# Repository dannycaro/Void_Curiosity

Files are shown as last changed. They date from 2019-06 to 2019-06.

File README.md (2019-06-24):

# Void_Curiosity

VoidCuriosity es el proyecto que están realizando un grupo de alumnos de 1º de Bachillerato del IES Vicente Aleixandre para la asignatura de Tecnología Industrial I y TIC I, basado en el proyecto abierto creado por @felixstdp, el cual se puede encontrar en [bricolabs](https://bricolabs.cc/wiki/proyectos/curiosity_btl), y en la versión creada por @javacasm

El proyecto consiste en un réplica a escala del famoso robot de investigación denominado como Curiosity de la NASA. Es un vehículo de exploración que puede superar terrenos difíciles y obstáculos con los que tendrían problemas otro tipo de vehículos. 

Para más información sobre nuestro proyecto podéis visitar la [web de nuestro proyecto](https://sites.google.com/iesvaleix.com/voidcuriosity)

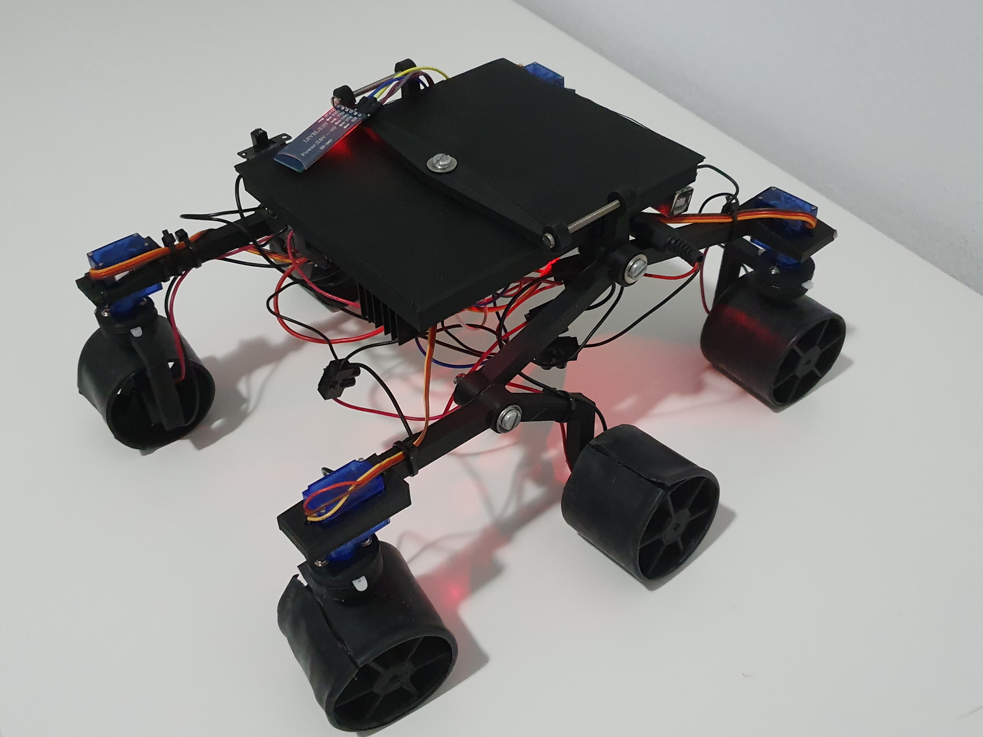
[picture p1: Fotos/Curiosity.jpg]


En el repositorio puedes encontrar:
- [Memoria del proyecto en PDF](https://github.com/dannycaro/Void_Curiosity/blob/master/Memoria%20curiosity.pdf)
- [Código de Arduino](https://github.com/dannycaro/Void_Curiosity/blob/master/Software/C%C3%B3digo%20Arduino/C%C3%B3digo%20v3.0)
- [Apk de la Aplicación](https://github.com/dannycaro/Void_Curiosity/blob/master/Software/VoidCuriosity.apk)
- [Aia de la Aplicación](https://github.com/dannycaro/Void_Curiosity/blob/master/Software/VoidCuriosity.aia)
- [Esquema electronico de conexión](https://github.com/dannycaro/Void_Curiosity/blob/master/Hardware/Esquema%20electrico%20definitivo%20.png)
- [Esquema en protoboard](https://github.com/dannycaro/Void_Curiosity/blob/master/Hardware/Protoboard%20definitiva.png)
- [Esquema en formato Fritzing fzz](https://github.com/dannycaro/Void_Curiosity/blob/master/Hardware/Curiosity_FINAL%20.fzz)

## LICENCIA
Este proyecto fue desarrollado durante el curso 2018/2019 en el IES Vicente Aleixandre de Sevilla en 1º de Bachillerato de Tecnología Industrial por Danny Caro, Alejandro Lauriño y Raúl Gimeno con el apoyo de su profesor Jose Pujol. Se distribuye con licencia [Creative Commons Attribution-ShareAlike 4.0 International License](http://creativecommons.org/licenses/by-sa/4.0/)

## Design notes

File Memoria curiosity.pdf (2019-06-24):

# Memoria del Voidcuriosity

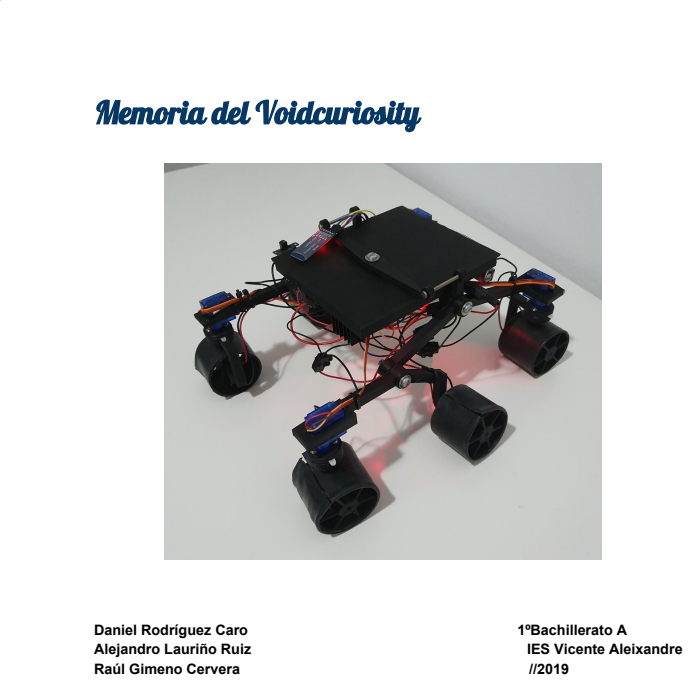
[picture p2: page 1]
Daniel Rodríguez Caro; 1ºBachillerato A; Alejandro Lauriño Ruiz; IES Vicente Aleixandre; Raúl Gimeno Cervera

Memoria proyecto curiosity

## Índice

Índice | 1
1. Finalidad del Sistema | 2
2. Hardware | 2
3. Software | 4
4. Funcionamiento | 6
5. Evaluación | 6
6. Bibliografía y webgrafía | 7

## 1. Finalidad del Sistema

El proyecto es una reproducción a escala 1:10 del astromóvil lanzado en la misión Mars Science Laboratory.
En un principio, enviamos las órdenes para mover los servos y hacer girar los motores a través del monitor serie, con el robot conectado al ordenador (pmv).
Cuando ya teníamos eso, pasamos a usar un módulo bluetooth y App Inventor para controlarlo remotamente desde un dispositivo móvil.
El sistema consta de 6 motores cc motrices (N20 dc motors) y 4 servomotores directrices (9g servo), además del mecanismo rocker-boogie que le permitirá superar obstáculos no muy complejos con facilidad. Gracias a este sistema y la estabilidad del móvil, podrá desenvolverse sin dificultades en superficies escarpadas y terrenos complejos.

## 2. Búsqueda de información

La mayor parte de la información ha sido conseguida en el repositorio del proyecto (https://bricolabs.cc/wiki/proyectos/curiosity_btl) que se encuentra en la web de Bricolabs y en los Github’s de @felixstpd y @javacasm (https://github.com/javacasm/curiosity_btl) los cuáles han sido una ayuda fundamental a la hora de realizar el proyecto.

## 3. Hardware

a. Esquema de entradas y salidas

b. Lista de materiales
Material | Cantidad
Placa Arduino MEGA | 1
Arduino sensor shield v5.0 | 1
L298 | 1
N20 dc motors | 6
9g servos | 4
18650 baterías | 2
Tornillería | General
c. Esquema de la protoboard

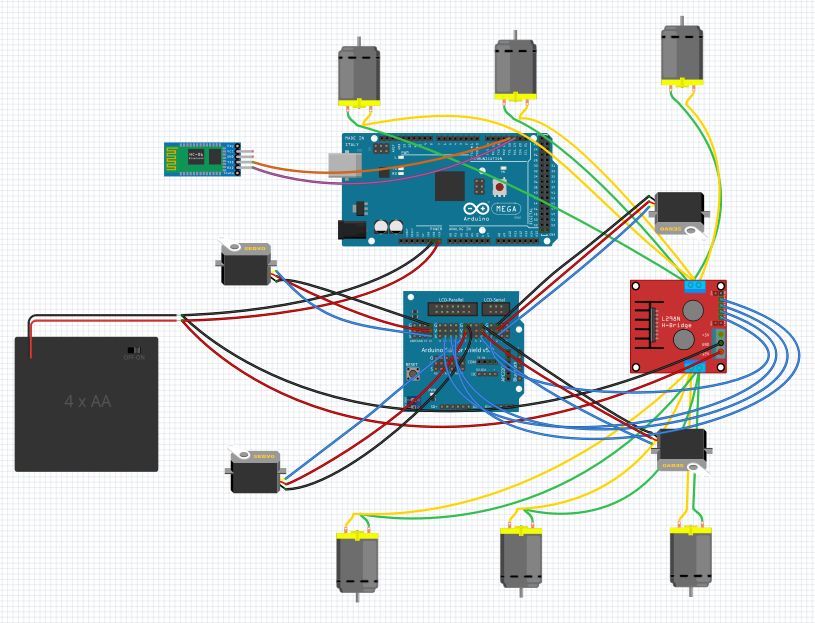
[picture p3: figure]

d. Esquema electrónico

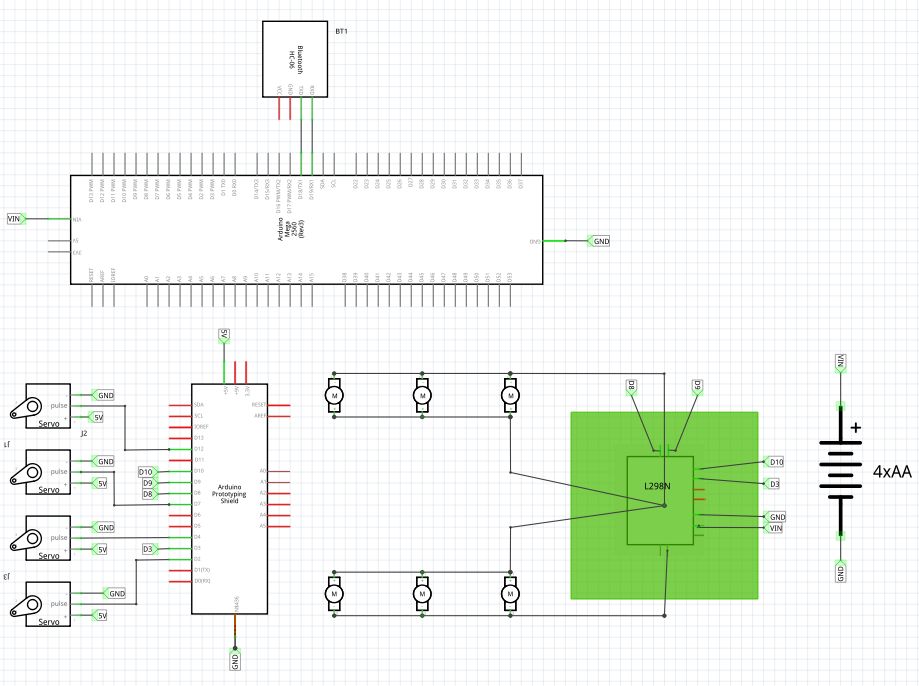
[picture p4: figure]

## 4. Software

/* Código v3.0
Proyecto Void Curiosity
Danny Caro
Alejandro Lauriño
Raúl Gimeno
1º BTO TIND-TIC
Basado en código de @javacasm
IES Vicente Aleixandre */

#include <Servo.h> //incluimos la librería para poder controlar los servomotores

//Definimos los pines de los servomotores
#define S1 12

#define S2 7

#define S3 4

#define S4 2

Servo s1, s2, s3, s4;

// Pines de control de los motores // Pines motor derecho
const int inA = 3;
const int inB = 10;
const int enA = 5;

// Pines motor izquierdo
const int inC = 9;
const int inD = 8;
const int enB = 6;

int value = 0; // variable para almacenar el valor numerico
int posS1, posS2, posS3, posS4; //Creamos las variables para almacenar la posición de los servos
int pasoServo = 5; // Incremento de posicion de los servos
int pwmValue = 0; // variable para enviar el codigo pwm al led

//Creamos una función para definir la posición inical de lo0s servos void setServosInitialState() {
posS1 = 97;
posS2 = 105;
posS3 = 98;
posS4 = 82;
}

// La velocidad va desde -255 a 255, con valores negativos moviendose hacia atras

int velocidad = 0;
int pasoVelocidad = 10; // Usaremos este incremento

// Nos permite dar velocidad a cada motor
void setSpeed(int enB, int speed) {
if (speed > 0) {
analogWrite(enB, speed);
}
else {
analogWrite(enB, - speed);
}
}

//Establecemos posicición de los servos y la velocidad de los motores void setState() {
setSpeed(enB, velocidad);
setSpeed(enA, velocidad);
s1.write(posS1);
s2.write(posS2);
s3.write(posS3);
s4.write(posS4);
}

// El motor gira en sentido horario void clockWise() {
digitalWrite(inA, LOW);
digitalWrite(inB, HIGH);
digitalWrite(inC, LOW);
digitalWrite(inD, HIGH);
}

// Función para que el motor gire en sentido antihorario void antiClockWise() {
digitalWrite(inA, HIGH);
digitalWrite(inB, LOW);
digitalWrite(inC, HIGH);
digitalWrite(inD, LOW);
}

void setup() {
// Configuramos los pines de los motores como salida pinMode(inA, OUTPUT);
pinMode(inB, OUTPUT);
pinMode(inC, OUTPUT);
pinMode(inD, OUTPUT);

// Configuramos los pines de los servos como salida pinMode(S1, OUTPUT);
pinMode(S2, OUTPUT);
pinMode(S3, OUTPUT);
pinMode(S4, OUTPUT);

// Configuramos las comunicaciones Serial1.begin(9600);

// Configuramos los servos s1.attach(S1);
s2.attach(S2);
s3.attach(S3);
s4.attach(S4);
setServosInitialState();
setState();
}

void loop() {
/*
Control de velocidad y giro por movimiento F el robot avanza
S detiene en seco
B el robot retrocede

Control de giro usando los servos L girar a la izquierda
R girar a la derecha
O servos rectos
*/

if (Serial1.available() > 0) {
char caracter = Serial1.read();
if (caracter >= '0' && caracter <= '9') {
//Acumula los datos numericos multiplicando por 10 el valor acumulado
value = (value * 10) + (caracter - '0'); // Resta 48 que es el valor decimal del 0 ASCII }
else if (caracter == '>') // uso > como finalizador
{
pwmValue = value; // Guarda el valor en la variable pwmValue value = 0; // Dejamos lista la variable para volver a escribir en ella }

else {
switch (caracter) {

case 'F': //Utilizamos para que el robot pueda caminar hacia delante clockWise();
velocidad = pwmValue;
break;
case 'B': //Utilizamos para que el robot pueda dar marcha atrás antiClockWise();
velocidad = pwmValue;
break;
case 'S': //Paramos los motores velocidad = 0;
break;
case 'L': // Mas giro a la izquierda posS1 -= pasoServo;
posS4 -= pasoServo;
posS3 += pasoServo;
posS2 += pasoServo;
break;
case 'O': // Ponemos los servomotores en la posición inicial setServosInitialState();
break;
case 'R': // Mas giro a la derecha
posS1 += pasoServo;
posS4 += pasoServo;
posS3 -= pasoServo;
posS2 -= pasoServo;
break;
}
}
// Vemos si nos hemos pasado de posiciones if (posS1 < 0) posS1 = 0;
if (posS2 < 0) posS2 = 0;
if (posS3 < 0) posS3 = 0;
if (posS4 < 0) posS4 = 0;
if (posS1 > 180) posS1 = 180; if (posS2 > 180) posS2 = 180;
if (posS3 > 180) posS3 = 180;
if (posS4 > 180) posS4 = 180;

// Vemos si nos pasamos en las velocidades
if (velocidad > 255 ) velocidad = 255;
if (velocidad < -255 ) velocidad = -255;

// Establecemos las posiciones de los servos y la velocidad de los motores setState();
}

## 5. Funcionamiento

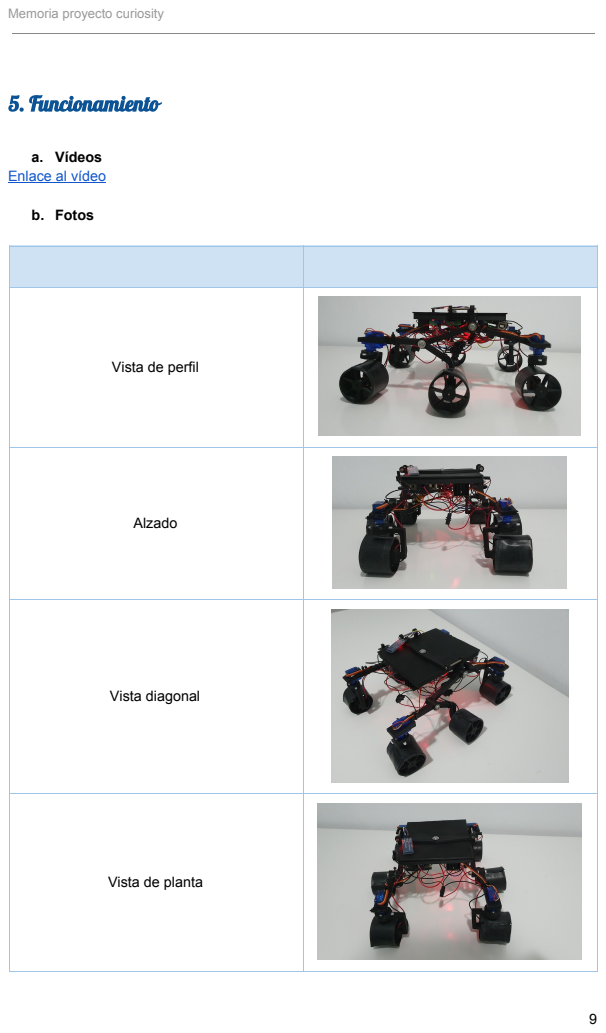
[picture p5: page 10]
b. Fotos

a. Vídeos
Enlace al vídeo (https://www.youtube.com/watch?v=UXL3HhqOG2k)

Vista de perfil

Alzado

Vista diagonal

Vista de planta

## 6. Evaluación

a. Qué funciona bien y qué se puede mejorar.
- Sistema rocker-bogie: El sistema funciona bien y consigue superar obstáculos de una altura del diámetro de la rueda más o menos. Podríamos mejorarlo haciendo que pase unos obstáculos de un poco más de inclinación.
b. Problemas que hemos tenido y soluciones.
- Cortocircuito: Tuvimos un cortocircuito al poner las pilas en el portapilas y entonces este se quemo. Solución: Revisamos todas las conexiones y utilizamos una fuente de alimentación.
- Pieza simétrica: Cuando hicimos la impresión 3D no hicimos la pieza simétrica de una de las patas, por lo que las ruedas quedaban mal posicionadas. Solución: Tuvimos que repetir la pieza haciéndola simétrica.
- Falta de pines PWM: Al comenzar el proyecto, en el hardware usábamos Arduino UNO pero nos faltaban pines PWM. Solución: Cambiamos Arduino UNO por el Arduino MEGA que tiene más pines PWM.
- Alimentación: No hemos tenido información de cómo alimentar el Arduino SensorShield v5.0. Solución: Hemos conectado la alimentación al JACK del Arduino Mega.
c. Propuestas para la mejora y ampliación del proyecto.
- WI-FI: Podríamos controlar el proyecto mediante WI-FI, y así poder manejarlo por internet.
- Cámara: Podríamos añadir una cámara al proyecto con la que podríamos ver por donde está en una pantalla.
- Sensor GPS: Al añadir un sensor de ubicación podríamos saber el lugar en el que se encuentra en cada momento.

## 7. Bibliografía y webgrafía

- https://github.com/javacasm/curiosity_btl
- https://bricolabs.cc/wiki/proyectos/curiosity_btl
- Twitter: @felixstdp @javacasm
